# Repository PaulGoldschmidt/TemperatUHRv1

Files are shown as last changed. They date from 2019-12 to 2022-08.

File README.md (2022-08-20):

**This repository is now due to the work on [TemperatUHR Version 2.0](https://github.com/PaulGoldschmidt/TemperatUHR) read-only and archived. Please only use version 2.0 if you consider building temperatUHR for yourself.**
---
## Welcome to TemperatUHR
This is a project by [Paul Goldschmidt](https://paul-goldschmidt.de/) which can smartly monitor the temperature of a fluid or a gas and notice you in case a certiain threshold is reached. It will even factor in the way to the sensor - so no energy gets wasted and the measured material just reaches the wanted temperature in the moment you'll arrive. 

## How to rebuild this project yourself 
The whole point-by-point instruction can be found here: [Click me!](https://github.com/PaulGoldschmidt/temperatUHR/blob/master/3_Documentation/instruction.md)

Check out the 3D-Model in Fusion360 by yourself and 3D-Print it: https://a360.co/2UUTSgx

You can also check out my easyEDA Project Page and scroll throu the BOM: [Click here](https://easyeda.com/manfred.weberpaul/paul-award-2020)

To get the app, download "blynk" from any appstore you like (except for windows mobile, sorry! :D) and scan the following qr-code:

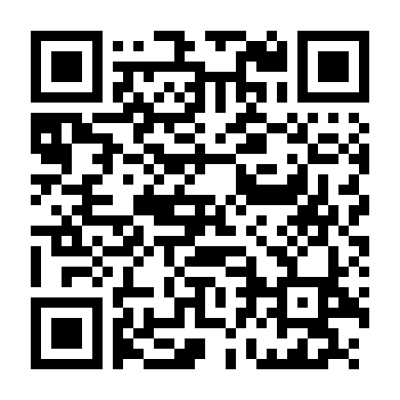
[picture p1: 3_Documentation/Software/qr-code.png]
QR-Code


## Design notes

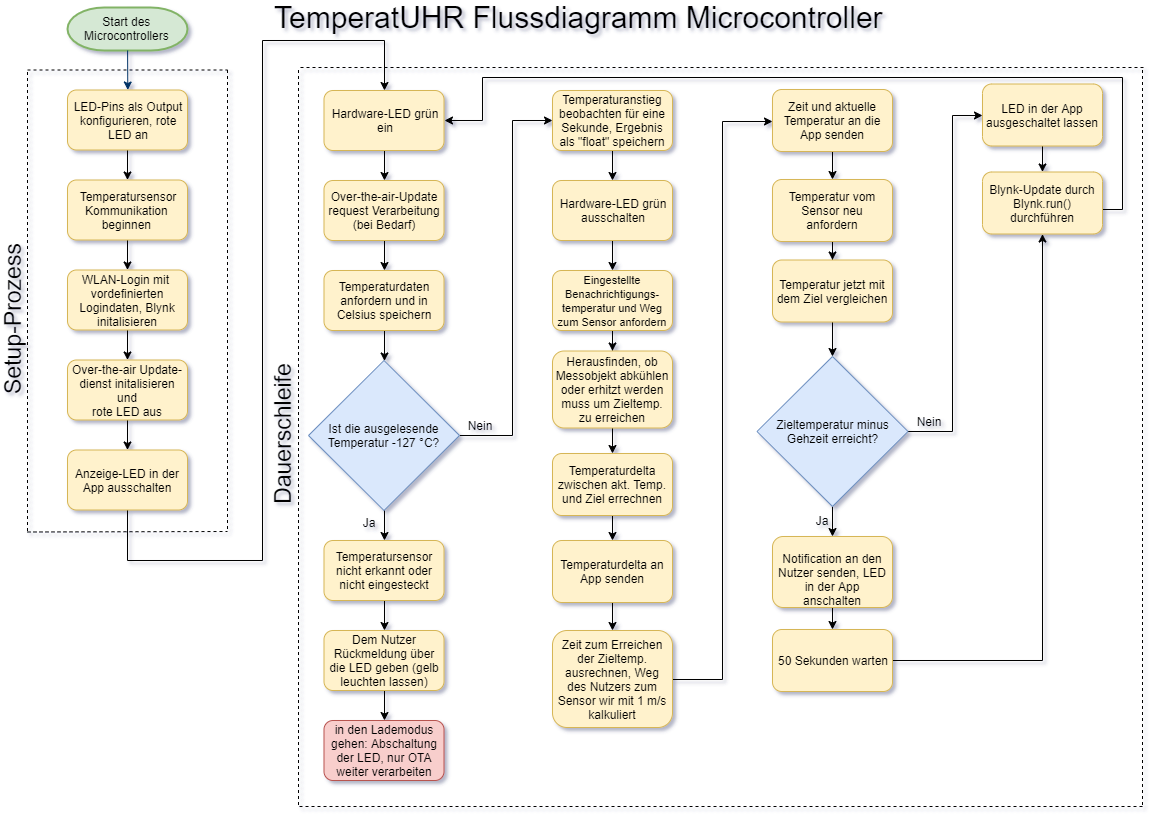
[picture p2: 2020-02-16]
3_Documentation/Software/Flowchart.png

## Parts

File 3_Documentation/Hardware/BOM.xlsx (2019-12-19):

ID | Name | Designator | Footprint | Quantity | Manufacturer Part | Manufacturer | Supplier
1 | LI-ION 3,7V 800mAh | BATT1 | NONE | 1 | Li-Ion_Cell_18650_Y02
2 | 68 | R1 | RES-TH_BD2.4-L6.3-P10.30-D0.6 | 1 | RNS14F68R0A520NH | Futaba Elec | LCSC
3 | USB-AF90 | CN1 | USB-A-TH_4PIN-FEMALE_USB-AF90 | 1 | USB-AF90 | ValuePro | LCSC
4 | WEMOS D1 MINI | MICROPROCESSOR | WEMOS_D1 MINI V2 | 1
5 | 4.7K | R4 | RES-TH_BD3.3-L9.0-P13.00-D0.6 | 1 | RN1WS4.7KΩFT/BA1 | TyoHM | LCSC
6 | 150 | R2 | RES-TH_BD2.5-L6.5-P10.50-D0.6 | 1 | MFR0W4F1500A50 | UniOhm | LCSC
7 | DS18B20 | U1 | TO-92-3_L4.9-W3.7-P1.27-L | 1 | DS18B20 | Youtai Semiconductor Co., Ltd. | LCSC
8 | Battery Protection tp4056 | U4 | TP4056E | 1 | Battery Protection tp4056
9 | 390 | R3 | RES-TH_BD2.5-L6.5-P10.50-D0.6 | 1 | MFR0W4F3900A50 | UniOhm | LCSC
10 | USB-AM90 | CN2,CN3 | USB-A_4PIN-MALE-AM90 | 2 | USB-AM90 | ValuePro | LCSC
11 | 5MMRGB | LED2 | LED-5.8-RGB | 1 | 5mmRGB | KENTO | LCSC
12 | Battery Management System | U2 | HX-2S-JH10 BMS | 1 | HX-2S-JH10 BMS board
13 | SS-12F23_SWITCH | U3 | SS-12F23 SWITCH | 1
14 | Step-Up-IC |  |  | 1 | FP6291 | Feeling Technonogy |  | http://www.feeling-tech.com.tw/km-master/ezcatfiles/cust/img/img/24/fp6291v070.pdf
15 | Charge-IC |  |  | 1 | ME4056 | MicrOne |  | https://datasheet.lcsc.com/szlcsc/Nanjing-Micro-One-Elec-ME4056SPG_C236731.pdf

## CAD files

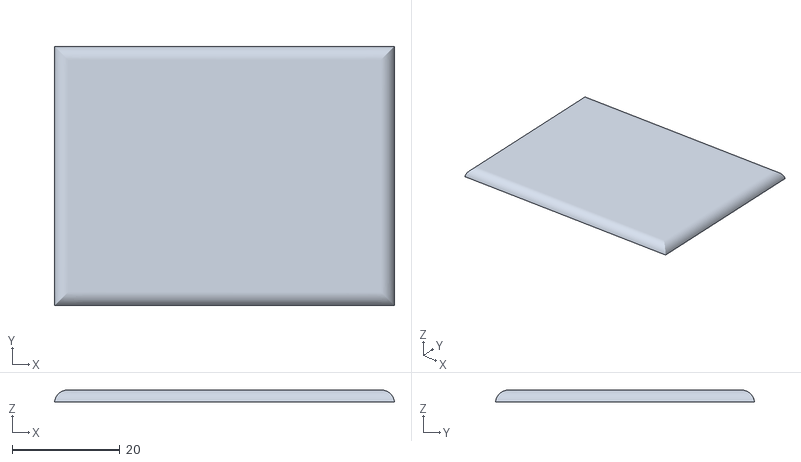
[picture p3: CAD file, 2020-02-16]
0_Hardware/3D-Enclosure/top_lid.stl
63.0 x 48.0 x 2.25

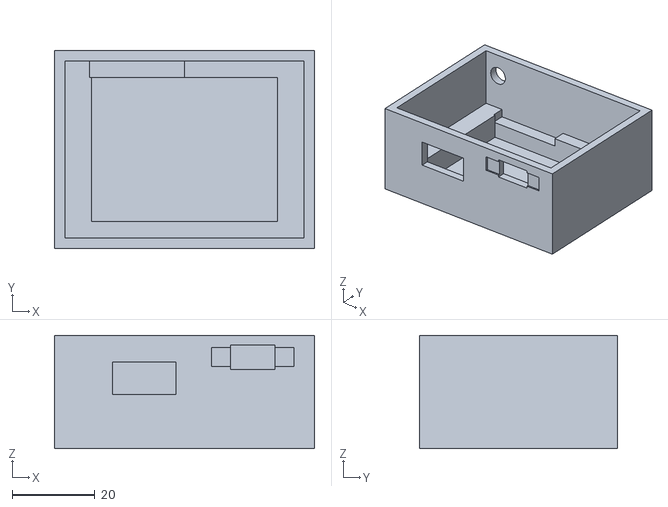
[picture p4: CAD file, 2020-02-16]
0_Hardware/3D-Enclosure/enclosure.stl
63.0 x 48.0 x 27.5

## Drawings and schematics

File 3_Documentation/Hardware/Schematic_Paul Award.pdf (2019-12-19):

# GND 4 SH¹ SH²

# GND 4 MH¹ MH²

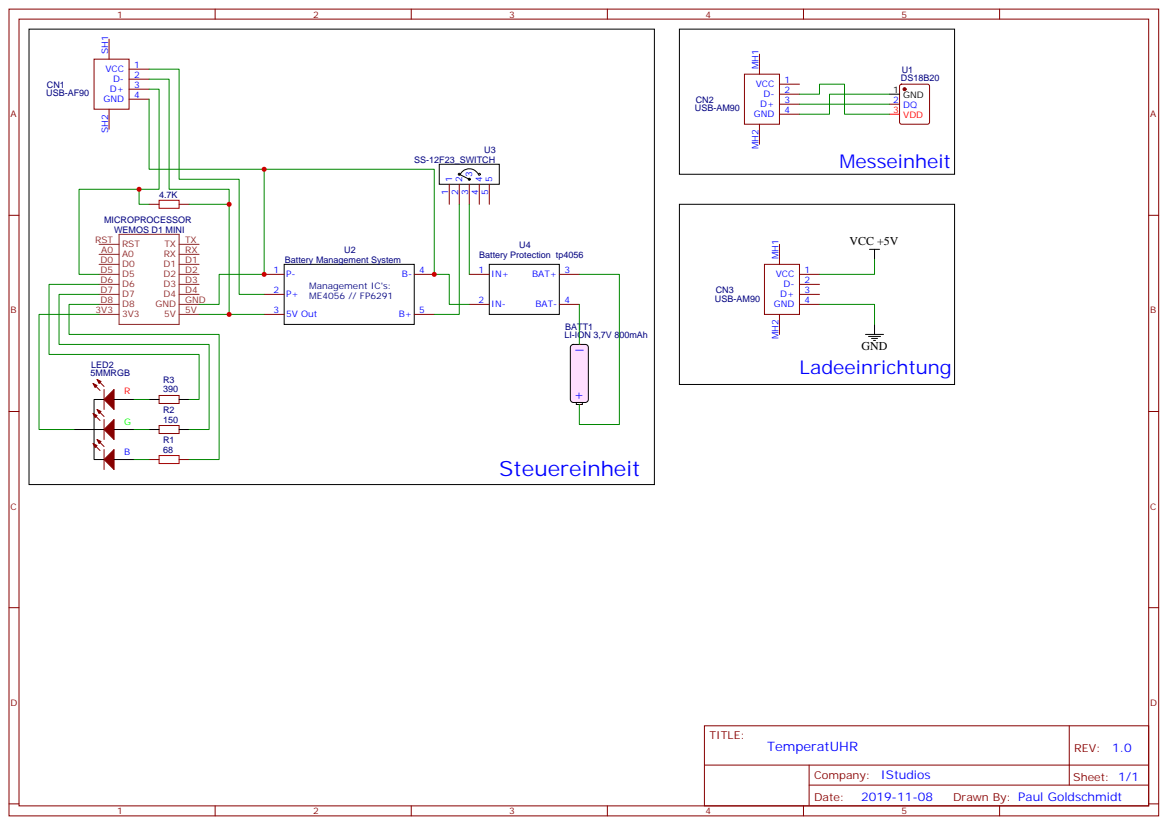
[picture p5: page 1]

Drawn By: Paul Goldschmidt

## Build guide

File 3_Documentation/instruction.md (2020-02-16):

# How to build this project
Hey! Thanks for considering building the project yourself! In this short instruction I will try to explain how to get your **TemperatUHR** up and running.
This is a step-by-step instruction, so let's begin:

 1. At first, check that you have a suited workspace. You will need a soldering iron as well as some typical consumeables (solder wire, cables and some flux)
 2. Get the GERBER file and order the pcbs on sites like JLCPCB.
 3. order all parts that you don't have allready. An BOM is in the EasyEDA Public worksheet.
 4. Wait till all the stuff arrives!
 5. Flash the D1 mini with the newest microcontroller software from this repo
 6. Begin soldering. I discoverd that the optimal sequence of soldering parts is the following: BPS - BMS - Resistors - USB-Port - Microcontroller - Battery to its connectors on the PCB
 Don't solder the LED and the switch to the PCB now, we'll do that later on.
 After finishing the PCB, solder the temperature probe to a USB-Plug, using the following pins:
 1 - Black Wire / 2 - DATA / 3 - GND / 4 - NC
 7.  now you can 3D-Print the enclosure. I printed the part in a local Makerspace using the Ultimaker 3, 0.06 mm layer hight and white PLA. It came out great and I can totally recommend the settings.
 8. After printing, wrap the battery in some felt and lay the battery down into the case. On top, put the PCB and reassure that the USB port is still accessible throu the hole in the case.
 9. After everything fits, secure it all with some hotglu. Not mutch is needed, everything should fit tight.
 10. Now, you can solder the LED and the switch to the marked connectors on the pcb.
 11. test run the hole thing. If everything goes as planed, the LED should start of red and than switch to yellow and go off after four seconds. Shut the device down, plug the temp. probe in and you should start seeing a flashing green light after turning the device back on. Perfect!
 12. Now you can put on the lid and use the device as intended.
 13. Success!
Definetly let me know when your own "TemperatUHR" works!
Cheers,
Paul from Heidelberg (Germany)

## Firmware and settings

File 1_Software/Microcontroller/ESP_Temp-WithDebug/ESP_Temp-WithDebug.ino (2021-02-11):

/*************************************************************

  TemperatUHR - Main Microcontroller Code
  In order to configure the program right, you have to change
  three things: Put thr right access-token into the space.
  Change the SSID and PASSWORD space to the right credentials
  for your WiFi.

  Code by Paul Goldschmidt, Febuary 2020.

 *************************************************************/
#define BLYNK_PRINT Serial //Debug console

#include <ESP8266WiFi.h> //all the libs are imported here - please double check that you have them installed.
#include <BlynkSimpleEsp8266.h>
#include <OneWire.h>
#include <DallasTemperature.h>
#include <ESP8266mDNS.h>
#include <WiFiUdp.h>
#include <ArduinoOTA.h>

#define ONE_WIRE_BUS 14 //the sensor is connected to pin #14
OneWire oneWire(ONE_WIRE_BUS);
DallasTemperature sensors(&oneWire);

// You should get Auth Token in the Blynk App.
// Go to the Project Settings (nut icon).
char auth[] = "YOUR_ACCESS_TOKEN";

// Your WiFi credentials.
// Set password to "" for open networks.
char ssid[] = "SSID";
char pass[] = "PASSWORD";

float metersToSensor, notificationTemp = 35, temperaturePerSec; //defining some global variables.
WidgetLED led1(V2); //an virtual LED is in the app "connected" to V2.

void setup()
{
  pinMode(12, OUTPUT); //the RGB-LED needs its pins initialised.
  pinMode(13, OUTPUT);
  pinMode(15, OUTPUT);
  digitalWrite(12, LOW); //red || the pins of the LED are put on High, so the LED won't light up..
  digitalWrite(13, HIGH); // Green
  digitalWrite(15, HIGH); //Blue
  WiFi.mode(WIFI_STA);
  // Debug console
  Serial.begin(9600);
  Serial.println("TemperatUHR Startup");
  sensors.begin(); //lets begin the communication with the senosor
  Blynk.begin(auth, ssid, pass);
  digitalWrite(12, HIGH);
  digitalWrite(13, LOW);
  ArduinoOTA.setHostname("TemperatUHR"); //Down below is all the OTA Stuff
  ArduinoOTA.onStart([]() {
    String type;
    if (ArduinoOTA.getCommand() == U_FLASH) {
      type = "sketch";
    } else { // U_SPIFFS
      type = "filesystem";
    }
    // NOTE: if updating SPIFFS this would be the place to unmount SPIFFS using SPIFFS.end()
    Serial.println("Start updating " + type);
  });
  ArduinoOTA.onEnd([]() {
    Serial.println("\nEnd");
  });
  ArduinoOTA.onProgress([](unsigned int progress, unsigned int total) {
    Serial.printf("Progress: %u%%\r", (progress / (total / 100)));
  });
  ArduinoOTA.onError([](ota_error_t error) {
    Serial.printf("Error[%u]: ", error);
    if (error == OTA_AUTH_ERROR) {
      Serial.println("Auth Failed");
    } else if (error == OTA_BEGIN_ERROR) {
      Serial.println("Begin Failed");
    } else if (error == OTA_CONNECT_ERROR) {
      Serial.println("Connect Failed");
    } else if (error == OTA_RECEIVE_ERROR) {
      Serial.println("Receive Failed");
    } else if (error == OTA_END_ERROR) {
      Serial.println("End Failed");
    }
  });
  ArduinoOTA.begin();
  Serial.println("Ready");
  Serial.print("IP address: ");
  Serial.println(WiFi.localIP());
  led1.off(); //check that the LED in the app is turned off.
}

BLYNK_WRITE(1) { //BLYNK.WRITE can now give the notification tempemperature back
  notificationTemp = param.asInt();
}

BLYNK_WRITE(3) { //BLYNK.WRITE can now give the way to TemperatUHR back
  metersToSensor = param.asInt();
}

void tempchange() { //this functions calcuates the temp difference that happens in 10 seconds.
  sensors.requestTemperatures();
  float temperaturestart = sensors.getTempCByIndex(0); // get the temperature on start
  delay(1000); //one second delay;
  sensors.requestTemperatures();
  float temperatureend = sensors.getTempCByIndex(0); // get the temperature after one second
  temperaturePerSec = temperatureend - temperaturestart; //calc the difference
}

void loop()
{
  digitalWrite(13, HIGH); //turn green LED off
  boolean CooldownMode; //in case the temperature of the liquid is higher than the set temperature
  ArduinoOTA.handle(); //handle OTA-Updates
  sensors.requestTemperatures(); //request temp sensor data
  float temperature = sensors.getTempCByIndex(0); //store it in the float temperature
  if (temperature == -127) { //this function will go into work when the sensor isnt connected.
    digitalWrite(12, LOW);
    digitalWrite(13, LOW);
    delay(4500);
    digitalWrite(12, HIGH);
    digitalWrite(13, HIGH);
    while (true) {
      ArduinoOTA.handle();
      delay(250);
    }
  }
  delay(50); //Wait 50 ms
  tempchange(); //calls the function to calc the temp. rise
  digitalWrite(13, LOW); //turns LED on
  BLYNK_WRITE(1); // reading the notification Temperature from App
  BLYNK_WRITE(3); // way from user to TemperatUHR
  float tempDelta; //calc the temp. Delta for the user to display.
  if (temperature > notificationTemp + 20) { //is the substance cooling down or not?
    CooldownMode = true;
    tempDelta = temperature - notificationTemp;
  }
  else {
    CooldownMode = false;
    tempDelta = notificationTemp - temperature;
  }
  Blynk.virtualWrite(V4, tempDelta); //push the temp. delta to the app
  float tempreached = tempDelta / temperaturePerSec; // i assume the user walks with v = 1m/s
  Blynk.virtualWrite(V5, tempreached);
  Blynk.virtualWrite(V0, temperature); //push all the other data to blynk
  Serial.print("Notification Temperature: ");
  Serial.println(notificationTemp);
  Serial.print("Temperature: ");
  Serial.println(temperature);
  Serial.print("Delta: ");
  Serial.println(tempDelta);
  Serial.print("CooldownMode: ");
  Serial.println(CooldownMode);
  Serial.print("Temp per Sec: ");
  Serial.println(temperaturePerSec); //serial debug
  sensors.requestTemperatures(); //reget the sensor data
  temperature = sensors.getTempCByIndex(0); // rewrite temperature
  if (CooldownMode == false) { //has the temp. reached yet?
    if (temperature >= notificationTemp - 5) {
      Blynk.notify("Temperatur erreicht!");
      led1.on();
      delay(50000); //wait 50s.
    }
    else {
      led1.off(); //the LED stays off.
    }
  }
  else {
    if (notificationTemp >= temperature + 5) {
      Blynk.notify("Temperatur erreicht!");
      led1.on(); //turn the LED on.
      delay(50000); //wait 50s.
    }
    else {
      led1.off(); //the LED stays off.
    }
  }
  Blynk.run(); //run the blynk update process.
}

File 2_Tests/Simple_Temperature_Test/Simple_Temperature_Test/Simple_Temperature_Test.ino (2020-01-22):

/********************************************************************/
// First we include the libraries
#include <OneWire.h> 
#include <DallasTemperature.h>
/********************************************************************/
// Data wire is plugged into pin 2 on the Arduino 
#define ONE_WIRE_BUS 14
/********************************************************************/
// Setup a oneWire instance to communicate with any OneWire devices  
// (not just Maxim/Dallas temperature ICs) 
OneWire oneWire(ONE_WIRE_BUS); 
/********************************************************************/
// Pass our oneWire reference to Dallas Temperature. 
DallasTemperature sensors(&oneWire);
/********************************************************************/ 
void setup(void) 
{ 
 // start serial port 
 Serial.begin(9600); 
 Serial.println("Dallas Temperature IC Control Library Demo"); 
 // Start up the library 
 sensors.begin(); 
} 
void loop(void) 
{ 
 // call sensors.requestTemperatures() to issue a global temperature 
 // request to all devices on the bus 
/********************************************************************/
 Serial.print(" Requesting temperatures..."); 
 sensors.requestTemperatures(); // Send the command to get temperature readings 
 Serial.println("DONE"); 
/********************************************************************/
 Serial.print("Temperature is: "); 
 Serial.print(sensors.getTempCByIndex(0)); // Why "byIndex"?  
   // You can have more than one DS18B20 on the same bus.  
   // 0 refers to the first IC on the wire 
   delay(1000); 
} 

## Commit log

2019-12-19 Begin of Hardware-design-process
    [BOM.xlsx]
2020-02-16 added the altarion pcb source.
    [Mainboard.pcbdoc]
2020-02-16 Added the gerber file.
2020-02-16 added 3D-STL-Files, merge with gitlab complete.
    [enclosure.stl, top_lid.stl]
2020-02-16 rebuild the Flowchart.
2022-08-20 Message about archival of TemperatUHR Version 1.
2022-08-20 Final link change before archival of TemperatUHR V1
